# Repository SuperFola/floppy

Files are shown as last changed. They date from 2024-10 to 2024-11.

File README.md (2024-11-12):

# Floppy keyboard

A 90x94mm hotswap 34 keys split choc v1 keyboard, in the footprint of a floppy disk.

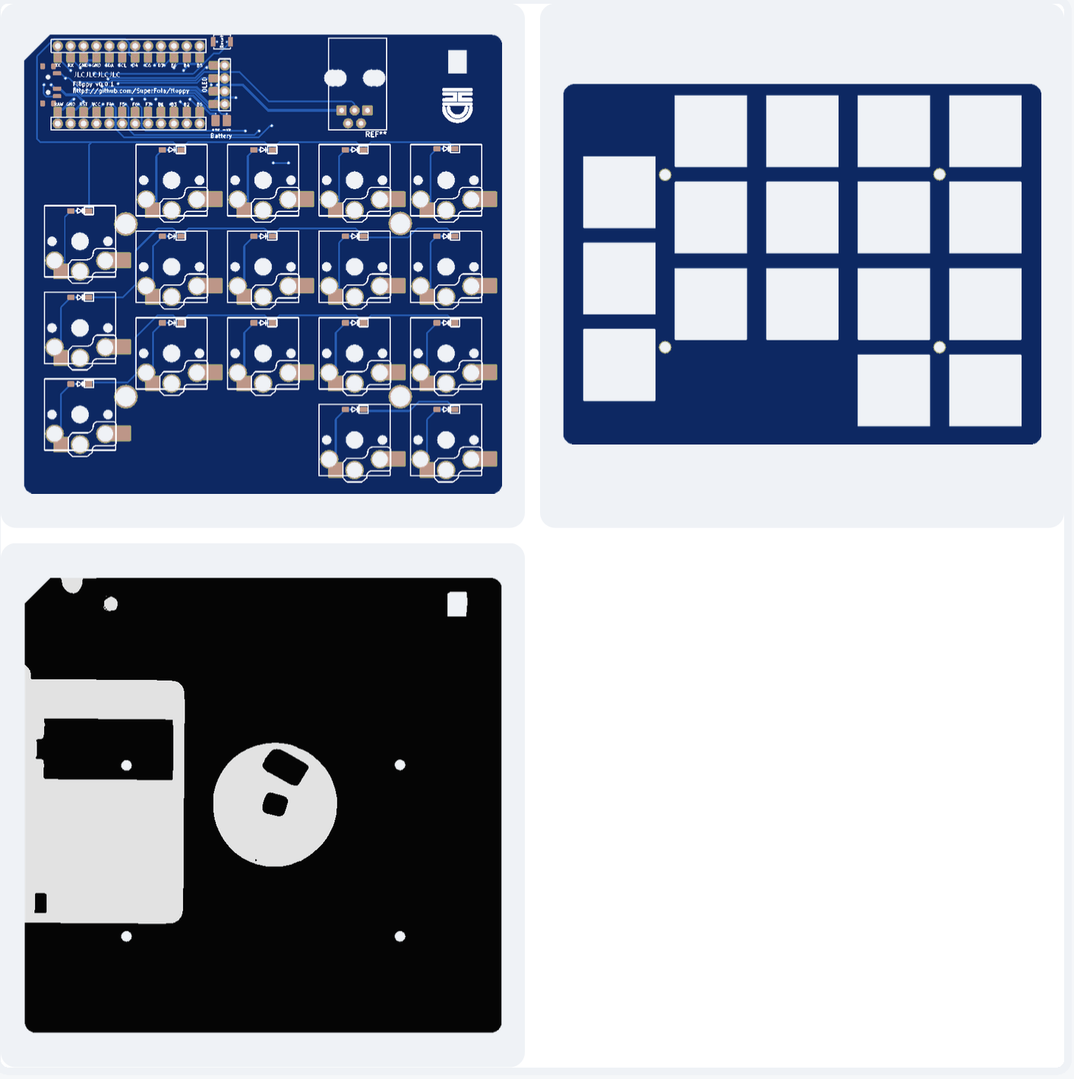
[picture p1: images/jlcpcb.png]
jlcpcb order


Final build

## Ordering

Gerbers to upload are under `gerbers/`.

Recommandations:
- top plate: 1.2mm
- back plate: 1.6mm
- pcb: 1.6mm

> ![NOTE]
> Remember to remove the order number on the top plate and back plate. On the PCB, there is a text that need to be used for the order number: "JLCJLCJLCJLC".

## Components for one keyboard

- 2 pro-micro compatible MCU (eg Liatris, Nice!Nano)
- 34 hotswap kailh choc v1 socket (PG1350)
- 34 choc v1 switches & keycaps
- 34 SMD diodes
- 2 RJ11 4P4C connectors (18mm x 11mm)
- 1 RJ11 4P4C cable that **needs to be straight** (when put side to side, the cables inside should match), otherwise **you will end up swapping VCC and GND, and putting the data pin to GND on the other half**

## More images

Side by side

Compared to a floppy disk

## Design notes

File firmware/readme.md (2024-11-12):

# Floppy

*The Floppy is an open source split keyboard based on the Sweep.*

* Keyboard Maintainer: [SuperFola](https://github.com/SuperFola)
* Hardware Supported: *Floppy + Liatris*
* Hardware Availability: [*Floppy Repository*](https://github.com/SuperFola/floppy)

Make example for this keyboard (after setting up your build environment):

    make floppy:default

Flashing example for this keyboard:

    make floppy:default:avrdude-split-right

See the [build environment setup](https://docs.qmk.fm/#/getting_started_build_tools) and the [make instructions](https://docs.qmk.fm/#/getting_started_make_guide) for more information. Brand new to QMK? Start with our [Complete Newbs Guide](https://docs.qmk.fm/#/newbs).

## Bootloader

Entering the bootloader:

<!-- * **Bootmagic reset**: Hold down the key at (0,0) in the matrix (usually the top left key or Escape) and plug in the keyboard -->
* **Physical reset button**: Briefly press the small button on the inner side of the PCB - you may have pads you must short instead
<!-- * **Keycode in layout**: Press the key mapped to `QK_BOOT` if it is available -->

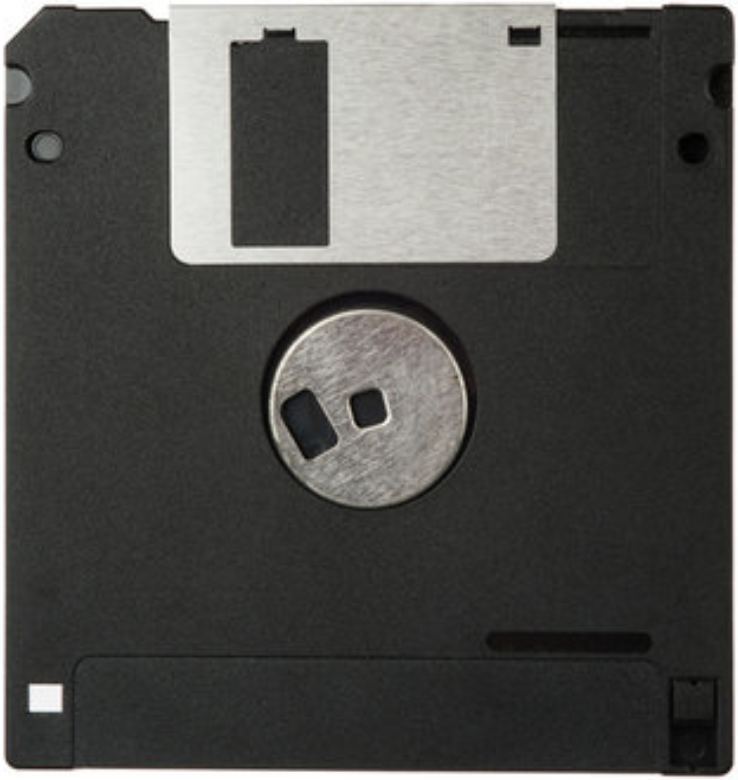
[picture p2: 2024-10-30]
images/base_silk.png

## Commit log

2024-10-25 Adding first version of the keyboard
    [floppy.kicad_pcb, floppy.kicad_sch, switch_plate.kicad_pcb]
2024-10-27 feat: moving the pinky column downward, adding backplate
    [backplate.kicad_pcb, floppy.kicad_pcb, switch_plate.kicad_pcb]
2024-10-27 chore: adding gerbers
2024-10-27 chore: adding pcb image
